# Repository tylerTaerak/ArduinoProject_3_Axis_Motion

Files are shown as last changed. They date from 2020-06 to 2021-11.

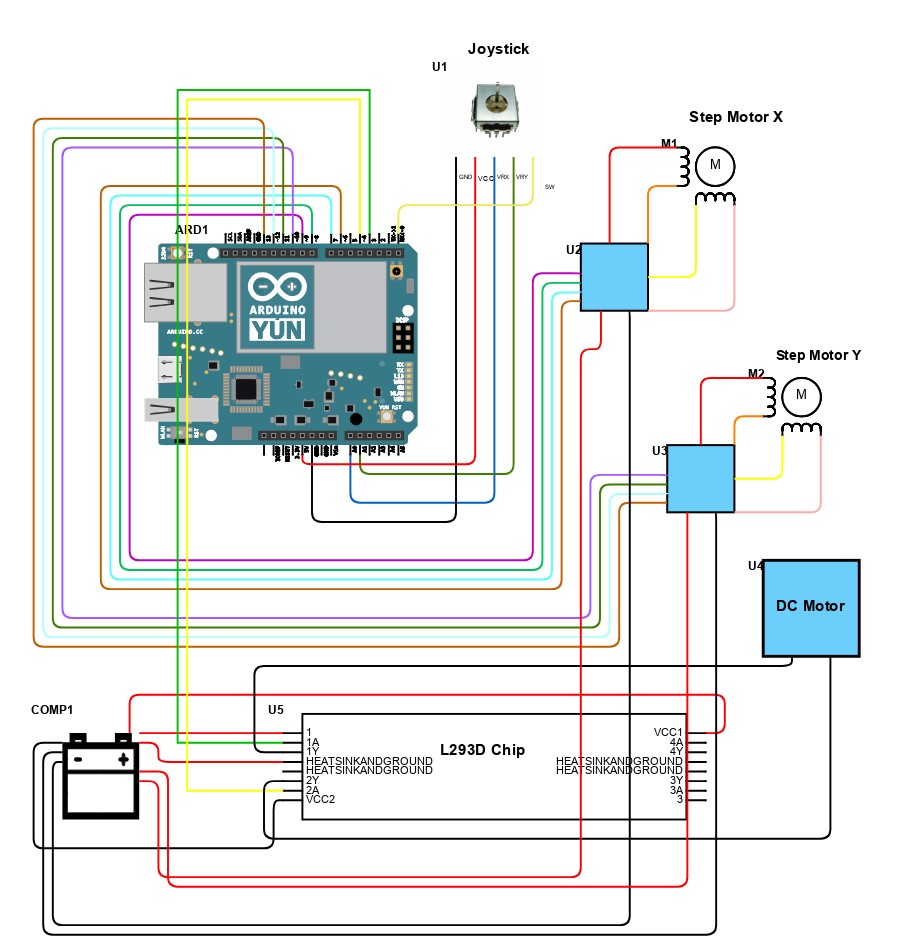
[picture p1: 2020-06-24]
ElectronicsSchematic.jpg

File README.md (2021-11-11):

# 3-Axis Motion System

I originally built this for a school project for a short 7-week Arduino class
I took a few years back. The first version of this was my final project for 
said class. 

Now, I have rebuilt this project from the ground up, using completely different
hardware and designs. The full assembly can be found in the `SolidWorks_Parts`
directory, along with the parts used in that assembly.

All the parts in the `Not_my_parts` directory are taken from McMaster-Carr
to use as reference parts. 

The code contains all the code needed to run the project. The project consists
of 3 NEMA-17 stepper motors and drivers, 3 reed switches, a simple 5-pin joystick,
and a Teensy microcontroller. 

Upload the code found in `Code/main` and wire up the parts accordingly, and move
the system around with the joystick.

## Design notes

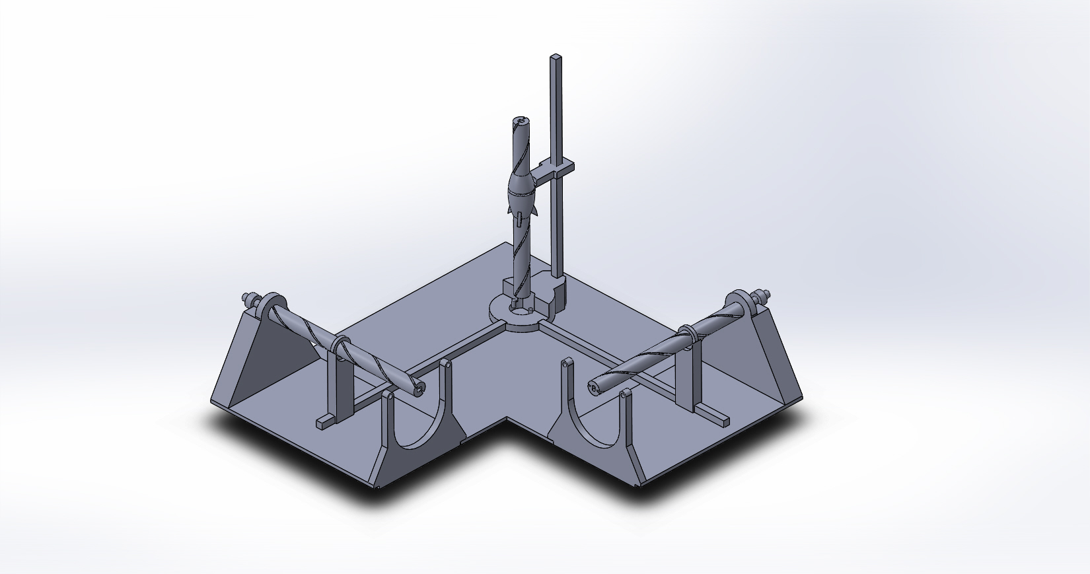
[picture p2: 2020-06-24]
ProjAsmb.JPG

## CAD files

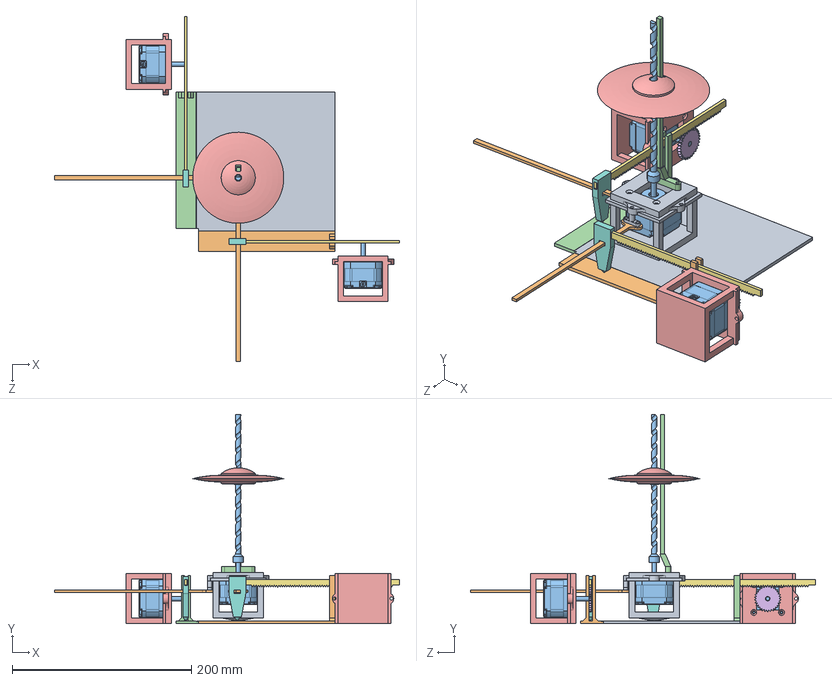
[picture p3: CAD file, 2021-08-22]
SolidWorks_Parts/FullAssembly.SLDASM
385.1 x 233.6 x 385.1 mm
BasePlate
FlangeX
6627T650_POSITION-CONTROL DC MOTOR x 3
FlangeY
MotorCarriage x 2
AxisGear x 2
Axis x 2
XYSlider x 2
MotorCarriageZ
ZAttachment x 2
ZAxis
ZStabilizer
MovingPart

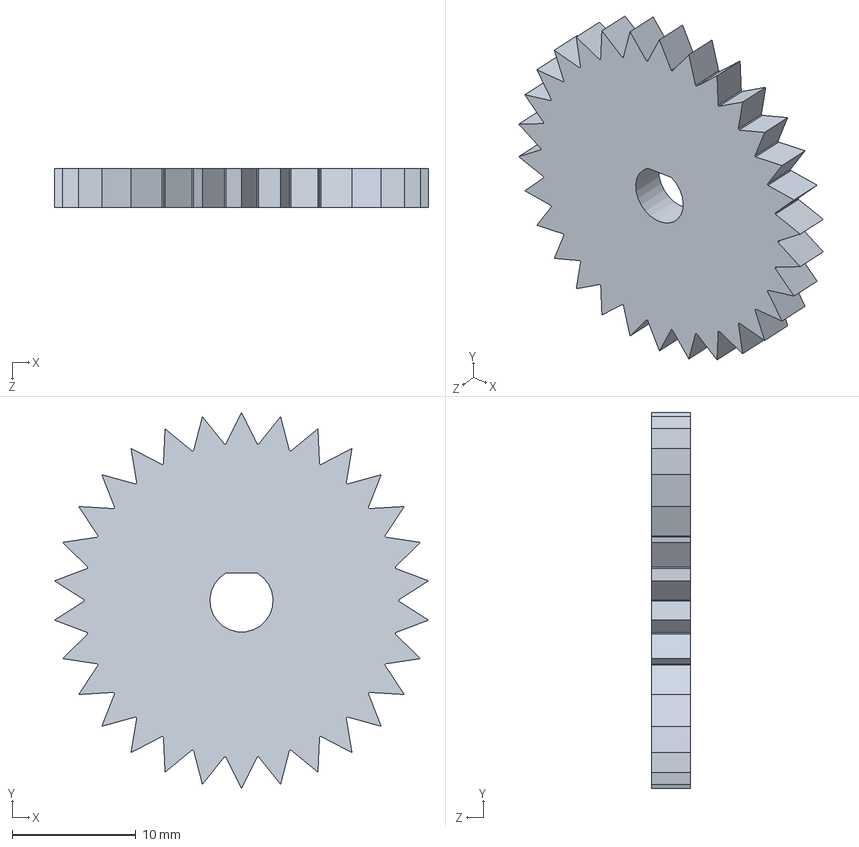
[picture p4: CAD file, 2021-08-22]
SolidWorks_Parts/AxisGear.SLDPRT
30.2 x 30.4 x 3.17 mm

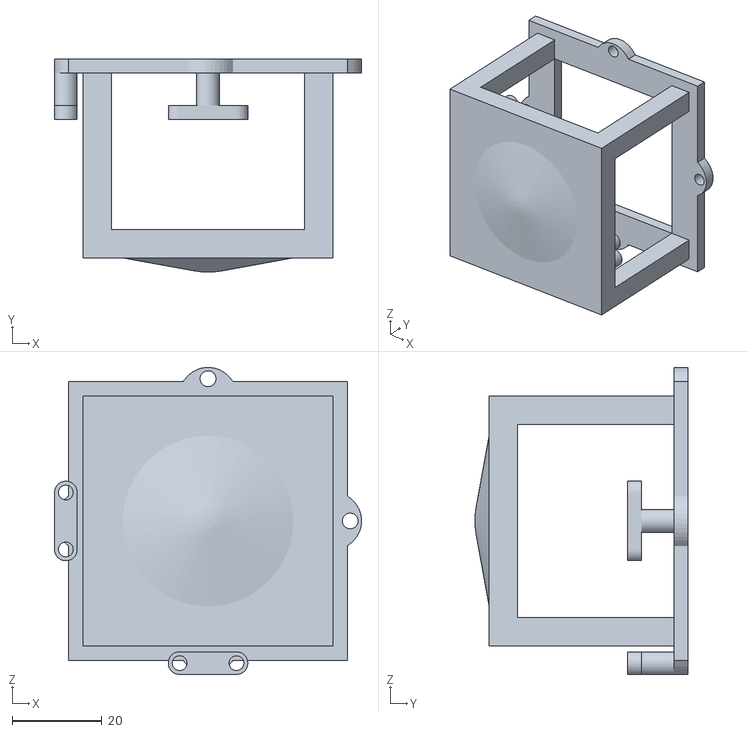
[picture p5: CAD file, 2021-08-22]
STLs/MotorCarriageZBottom.STL
68.6 x 47.6 x 68.6

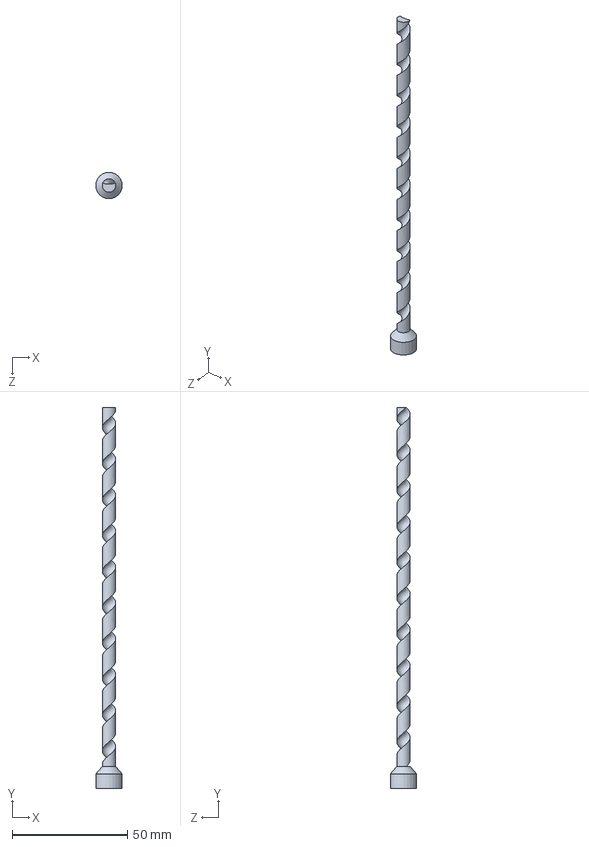
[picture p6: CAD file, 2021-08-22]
SolidWorks_Parts/ZAxis.SLDPRT
11.4 x 165.1 x 11.4 mm

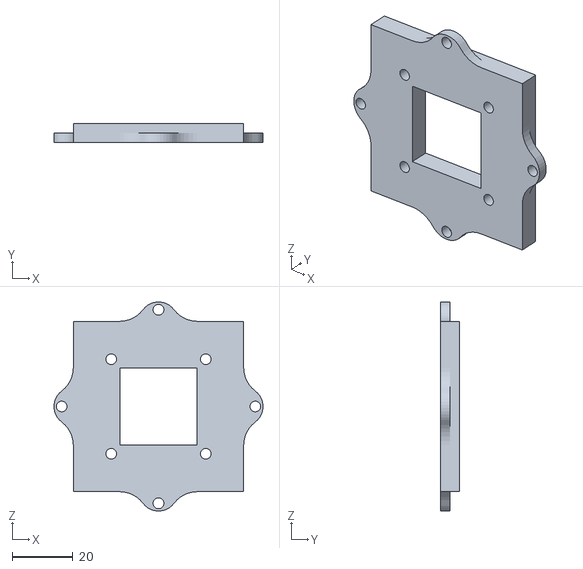
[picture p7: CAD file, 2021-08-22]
STLs/MotorCarriageZTop.STL
68.5 x 6.35 x 68.5

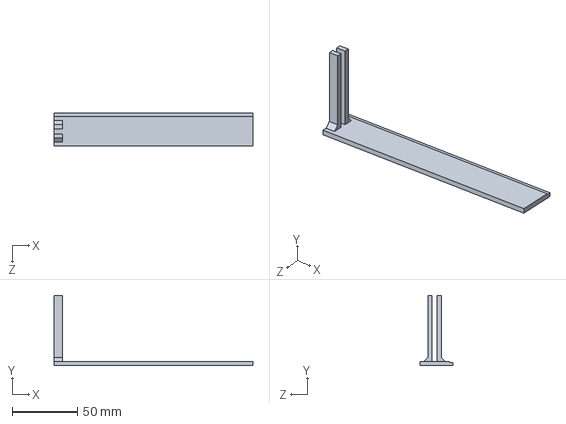
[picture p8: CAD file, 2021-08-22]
SolidWorks_Parts/FlangeY.SLDPRT
152.4 x 54.0 x 25.4 mm

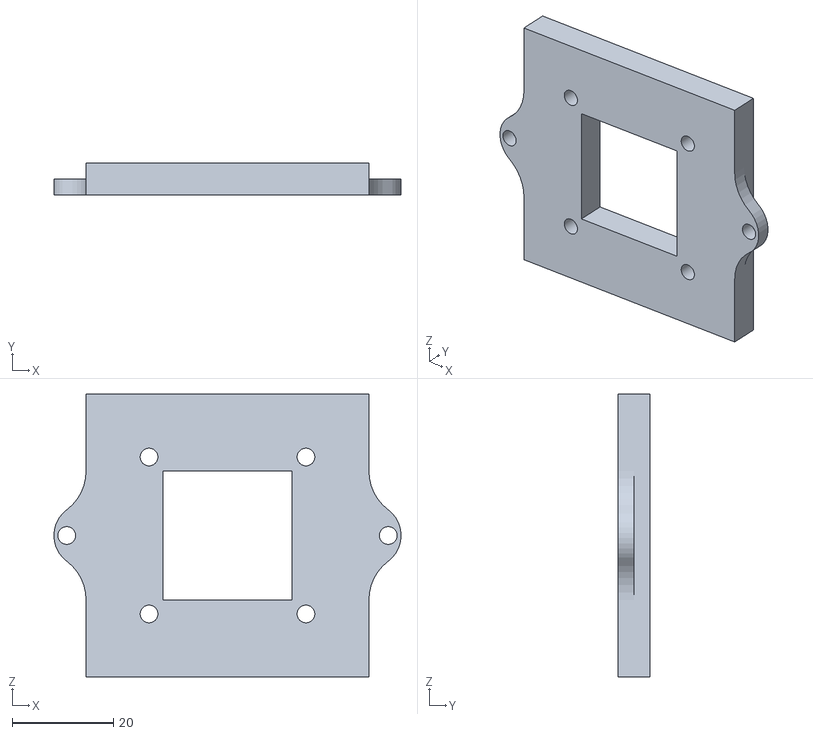
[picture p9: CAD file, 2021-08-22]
STLs/MotorCarriageTop.STL
68.5 x 6.35 x 55.9

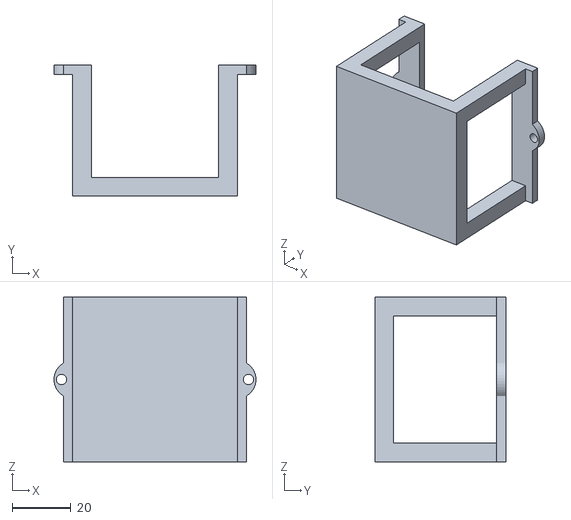
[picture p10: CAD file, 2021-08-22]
STLs/MotorCarriageBottom.STL
68.5 x 44.5 x 55.9

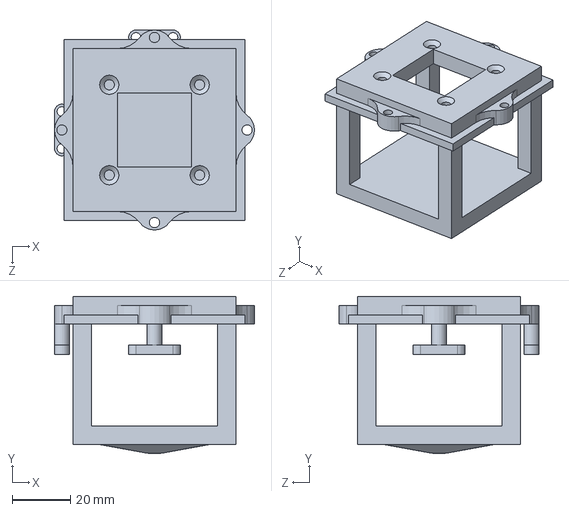
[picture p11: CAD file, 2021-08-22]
SolidWorks_Parts/MotorCarriageZ.SLDPRT
68.6 x 54.0 x 68.6 mm

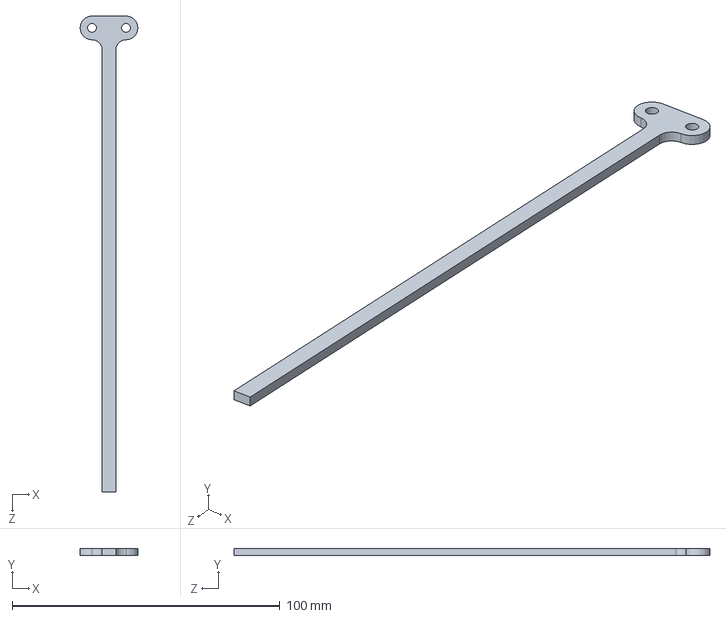
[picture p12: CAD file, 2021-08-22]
SolidWorks_Parts/ZAttachment.SLDPRT
21.6 x 2.54 x 177.8 mm

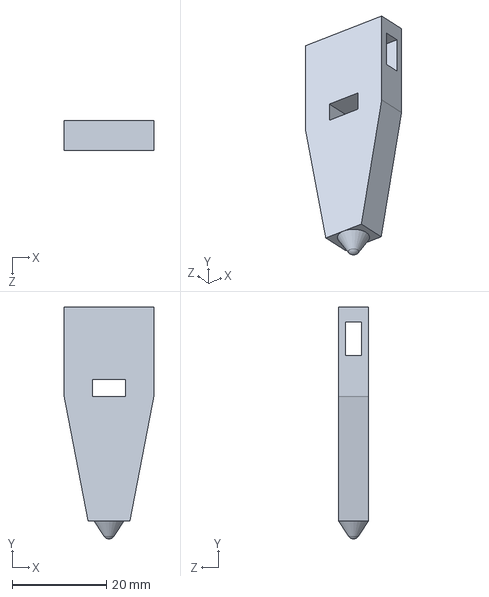
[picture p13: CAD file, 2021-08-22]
SolidWorks_Parts/XYSlider.SLDPRT
19.1 x 49.3 x 6.35 mm

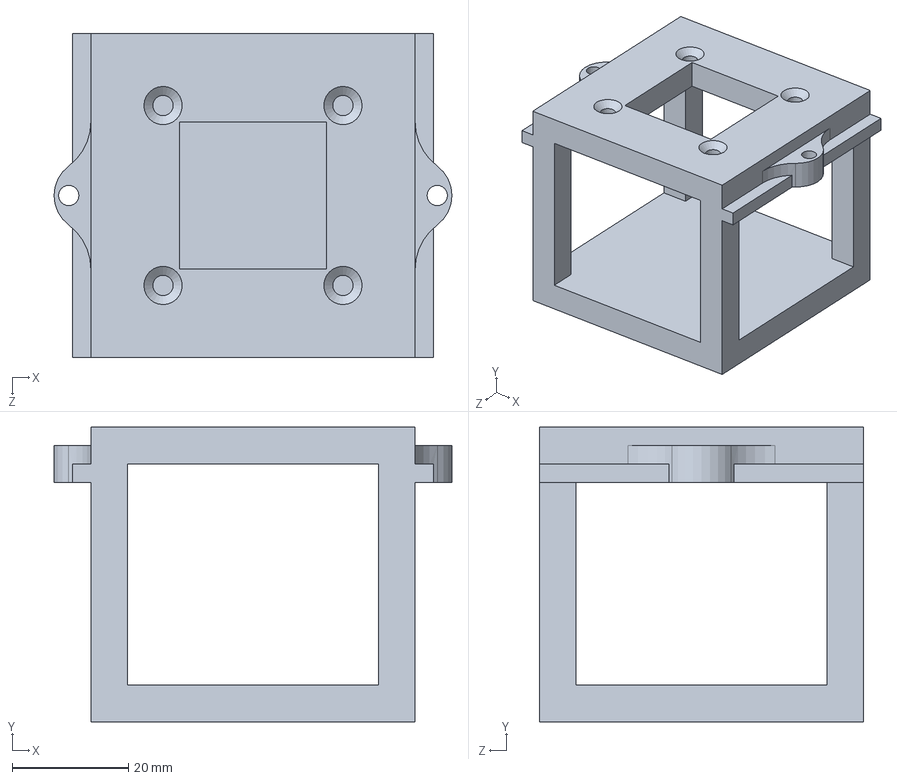
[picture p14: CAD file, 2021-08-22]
SolidWorks_Parts/MotorCarriage.SLDPRT
68.6 x 50.8 x 55.9 mm

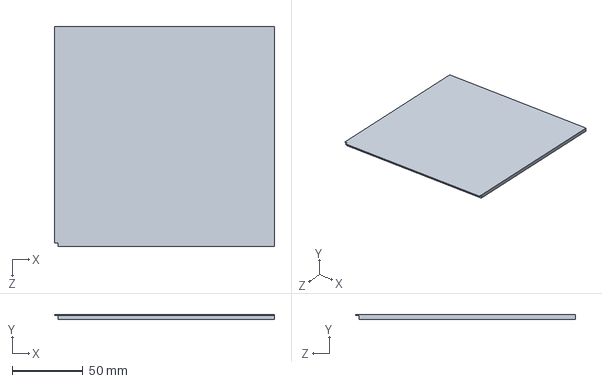
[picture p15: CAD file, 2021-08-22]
SolidWorks_Parts/BasePlate.SLDPRT
154.9 x 3.17 x 154.9 mm

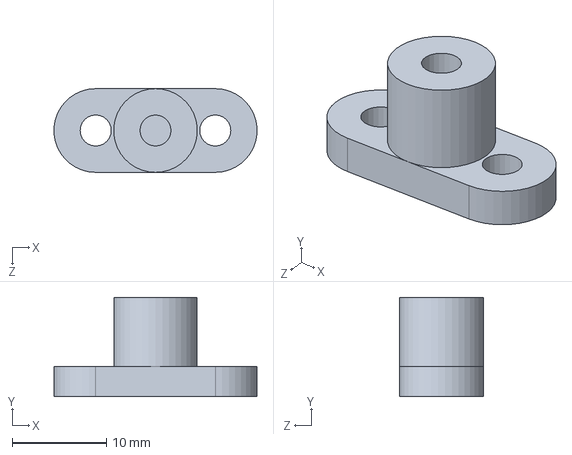
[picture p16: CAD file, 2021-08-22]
SolidWorks_Parts/AxisCoupling.SLDPRT
21.6 x 10.5 x 8.89 mm

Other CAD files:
SolidWorks_Parts/FlangeX.SLDPRT
SolidWorks_Parts/Axis.SLDPRT
SolidWorks_Parts/MovingPart.SLDPRT
SolidWorks_Parts/ZStabilizer.SLDPRT
Not_my_parts/6627T650_POSITION-CONTROL DC MOTOR.SLDPRT
STLs/Axis.STL
STLs/AxisCoupling.STL
STLs/AxisGear.STL
STLs/BasePlate.STL
STLs/FlangeX.STL
STLs/FlangeY.STL
STLs/MovingPart.STL
STLs/XYSlider.STL
STLs/ZAttachment.STL
STLs/ZAxis.STL
STLs/ZStabilizer.STL

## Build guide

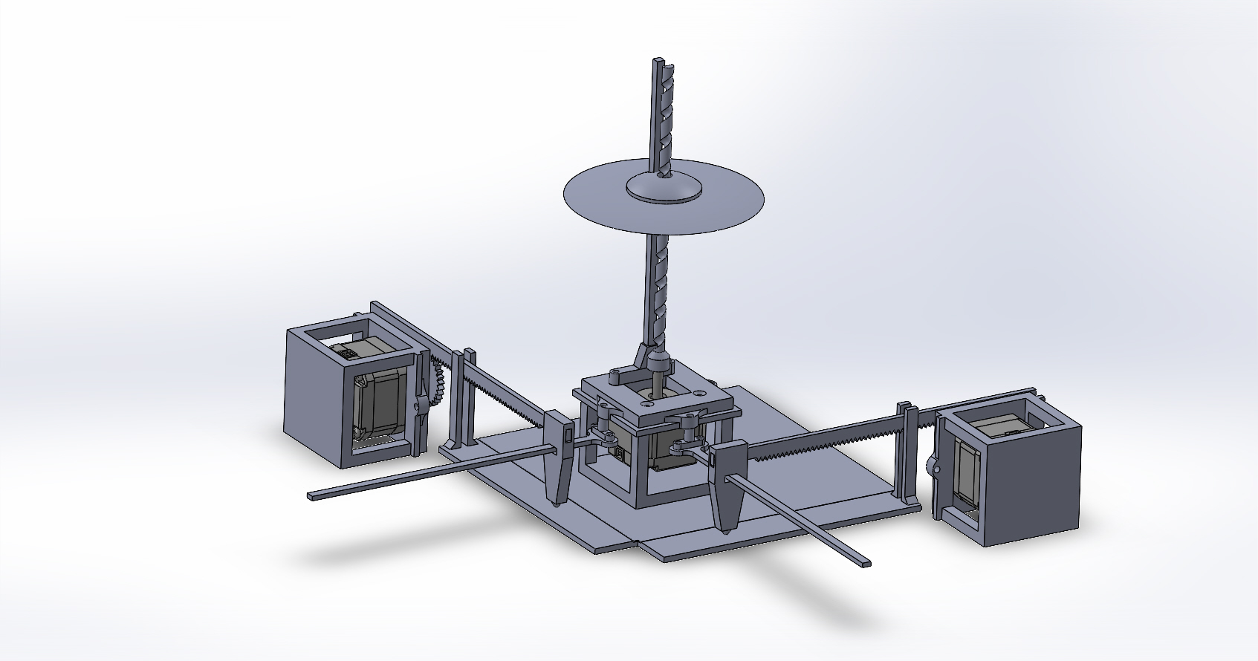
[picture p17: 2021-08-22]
FullAssembly.JPG

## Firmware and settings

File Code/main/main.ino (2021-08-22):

/**
  * @author Tyler
  * 
  * This is a single-file program for running the 3-Axis Motion System.
  * 
  * The 3-Axis Motion System was originally a school project of mine, which I
  * decided to completely refactor to make it more workable and to use some
  * of my newer experience and skills in microcontrollers and C++.
  * 
  * The output of the program is directed toward 3 NEMA-17 stepper motors, driven by
  * TB6600 stepper driver motors, and the input of the program is pulled from a simple joystick.  
  * The movement of the joystick controls the X- and Y-axes, while the button on it controls
  * whether the Z-axis moves up or down.
  * 
  * In addition to this, the endstops are reed switches, which will go HIGH if a
  * magnet comes close to them.  Magnets will be affixed to the sliders on each axis,
  * which will give the motion system the ability to find the (0, 0, 0) coordinate 
  * of the system.
  * 
  * All global definitions are done up front, including all pins, as well as a handful
  * of constants and a global variable storing the coordinates of the system. The setup()
  * and loop() functions follow, defining pinouts in the setup() function. The functions called
  * by the setup() and loop() functions come after, until the end of the program
  */


/*
 * x, y, and z axes represented as integers for extra readability
 * 
 * { x: 0, y: 1, z: 2 }
 */
#define x 0
#define y 1
#define z 2


/*
 * Pin Setup for the control joystick (JOY), step and direction pins for each stepper motor (STEP_PINS
 * and DIR_PINS), and reed switch endstops (ENDSTOPS)
 */
const int JOY[3] = { 38, 39, 0 };     // pins 38 and 39 on the Teensy++ 2.0 are analog pins
const int PUL_PINS[3] = { 1, 3, 5 };
const int DIR_PINS[3] = { 2, 4, 6 };
const int ENDSTOPS[3] = { 7, 8, 9 };


/*
 * Global variable to keep current coordinates (defined in the home_axes() function, 
 * which is called in the setup() function).  Constant values also defined for the maximum
 * number of steps for each axis in MAX.
 */
int coordinates[3];
const int MAX[3] = { 382, 382, 382 };


/*
 * Setup Function
 * 
 * Defines pin modes for each digital pin except for the ones already defined in the
 * stepper motor definitions above. Also sets the speed of each stepper motor and homes
 * each axis to 0.
 */
void setup() {
    pinMode( PUL_PINS[0], OUTPUT );
    pinMode( PUL_PINS[1], OUTPUT );
    pinMode( PUL_PINS[2], OUTPUT );

    pinMode( DIR_PINS[0], OUTPUT );
    pinMode( DIR_PINS[1], OUTPUT );
    pinMode( DIR_PINS[2], OUTPUT );
  
    pinMode( ENDSTOPS[0], INPUT_PULLUP );
    pinMode( ENDSTOPS[1], INPUT_PULLUP );
    pinMode( ENDSTOPS[2], INPUT_PULLUP );
    
    pinMode( JOY[2], INPUT_PULLUP );

    home_axes();
    coordinates[0] = 0;
    coordinates[1] = 0;
    coordinates[2] = 0;
}


/*
 * Loop Function
 * 
 * Handles movement for each axis repeatedly on loop, using the handle() function
 */
void loop() {
    handle( x ); // handles movement in x direction
    handle( y ); // handles movement in y direction 
    handle( z ); // handles movement in z direction
}


/*
 * Homes each axis to 0, using the reed switch endstops
 */
void home_axes(){
    while( digitalRead( ENDSTOPS[x] ) == 0 || 
        digitalRead( ENDSTOPS[y] ) == 0 || 
        digitalRead( ENDSTOPS[z] ) == 0 ){
                  
        if( digitalRead( ENDSTOPS[x] ) == 0 ){
             step_motor( x, -1 );
        }
        if( digitalRead( ENDSTOPS[y] ) == 0 ){
            step_motor( y, -1 );
        }   
        if( digitalRead( ENDSTOPS[z] ) == 0 ){
            step_motor( z, -1 );
        }
    }
}


/*
 * Returns a value depending on if the proposed move is valid within the coordinate system
 */
int validate( int axis, int value ){
    if ( coordinates[axis] + value > MAX[axis] ){
        return MAX[axis] - coordinates[axis];
    }
    if ( coordinates[axis] + value < 0 ) {
        return -coordinates[axis];
    }
    return value;
}


/*
 * Handle function for each axis (x: 0, y: 1, z: 2)
 * 
 * X and Y give a number between 0 and 5 steps depending on how far the joystick was pushed,
 * which gets a validation check from the validate() function
 * 
 * Z gets either 5 or -5 steps depending on if the joystick button is pressed or not. Also gets checked
 * by the validate() function
 */
void handle( int axis ){
    int dir;
    switch( axis ){
      case x:
        	dir = analogRead( JOY[x] );
  	      step_motor( x, validate( x, dir/100 ) );
          break;
      case y:
          dir = analogRead( JOY[y] );
  	      step_motor( y, validate( y, dir/100 ) );
          break;
      case z:
          dir = digitalRead( JOY[z] );
  	      if ( dir == 0 ){
  	    	    step_motor( z, validate( z, -5 ) );
  	      } 
  	      else {
  	    	    step_motor( z, validate( z, 5 ) );
  	      }
          break;
    }
}


/*
 * Function controlling the stepping of motors.
 * 
 * Relays instructions to the step and direction
 * pins of the targeted stepper motors. The direction
 * is defined by whether the number of steps given
 * to the function is positive or negative.
 * 
 * The motor will receive a step signal every 2 milliseconds,
 * as time is delayed for 1000 microseconds between switching
 * the pin on and off
 */
void step_motor( int axis, int steps ){
    coordinates[axis] += steps;
    if ( steps > 0 ) {
        digitalWrite( DIR_PINS[axis], HIGH );
    }
    if ( steps < 0 ) {
        digitalWrite( DIR_PINS[axis], LOW );
        steps = -steps;
    }

    for ( int i=0; i<steps; i++ ) {
        digitalWrite( PUL_PINS[axis], HIGH );
        delayMicroseconds( 1000 );
        digitalWrite( PUL_PINS[axis], LOW );
        delayMicroseconds( 1000 );
    }
}

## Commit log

2020-06-24 files added
    [3AxisSlider.STL, AxisBase.STL, AxisRingAtch.STL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]
2020-06-24 Added electronics schematics to repo
2021-08-22 full rework of project -- new model, new code
    [6627T650_POSITION-CONTROL DC MOTOR.SLDPRT, Axis.SLDPRT, Axis.STL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]
2021-08-22 removed old/unneccessary files
    [3AxisSlider.STL, AxisBase.STL, AxisRingAtch.STL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]
2021-11-11 moved SolidWorks parts and assembly to their own directory
    [Axis.SLDPRT, AxisCoupling.SLDPRT, AxisGear.SLDPRT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]
